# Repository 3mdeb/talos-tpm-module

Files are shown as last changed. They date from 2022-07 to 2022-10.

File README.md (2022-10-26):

# talos-tpm-module

TPM module design for
[Raptor CS Talos II](https://raptorcs.com/content/TL2WK2/intro.html) board.

**Revision 1.1 changelog:**

+ The main change is that the main connector is soldered from the bottom.

+ Jumper is also soldered from the bottom.

+ The arrangement of components has been slightly modified

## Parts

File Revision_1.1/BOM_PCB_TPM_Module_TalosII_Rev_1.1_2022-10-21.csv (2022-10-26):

ID | Name | Designator | Footprint | Quantity | Manufacturer Part | Manufacturer | Supplier | Supplier Part | Price
1 | 1uF | C1 | C1206 | 1 | CL31B105KBHNNNE | SAMSUNG | LCSC | C1848 | 0.014
2 | 100nF | C2,C3 | C1206 | 2 | CL31B104KBCNNNC | SAMSUNG | LCSC | C24497 | 0.013
3 | JUMPER2 | J1 | HDR-TH_2P-P2.54-V-M-1 | 1 | Jumper2 | null | LCSC | C2940092
4 | 4.7kΩ | R1 | R1206 | 1 | RMC12064.7K5%N | Tyohm | LCSC | C269760 | 0.007
5 | SLB9645TT12FW13333XUMA2 | U1 | PG-TSSOP-28_L9.7-W4.4-P0.65-LS6.4-BL | 1 | SLB9645TT12FW13333XUMA2 | Infineon(英飞凌) | LCSC | C2651707 | 2.584
6 | 220R-2*10P H=8.5MM Ytype Gold-plated black | H2 | HDR-TH_20P-P2.54-H-F-R2-C10-S2.54-W10.2 | 1 | 220R-2*10P H=8.5MM Ytype Gold-plated black | Ckmtw | LCSC | C124406 | 0.319

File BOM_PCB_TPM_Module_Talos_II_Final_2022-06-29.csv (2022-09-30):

ID | Name | Designator | Footprint | Quantity | Manufacturer Part | Manufacturer | Supplier | Supplier Part | Price
1 | 1uF | C1 | C1206 | 1 | CL31B105KBHNNNE | SAMSUNG | LCSC | C1848 | 0.026
2 | 100nF | C2,C3 | C1206 | 2 | CL31B104KBCNNNC | SAMSUNG | LCSC | C24497 | 0.014
3 | DS1024-2*10R2 CONNFLY | H2 | HDR-TH_20P-P2.54-H-F-R2-C10-S2.54-W10.2 | 1 | DS1024-2*10R2 | CONNFLY | TME | ZL263-20DG | 0.429
4 | 4.7kΩ | R1 | R1206 | 1 | RMC12064.7K5%N | Tyohm | LCSC | C269760 | 0.007
5 | SLB9645TT12FW13333XUMA2 | U1 | PG-TSSOP-28_L9.7-W4.4-P0.65-LS6.4-BL | 1 | SLB9645TT12FW13333XUMA2 | Infineon(英飞凌) | LCSC | C2651707 | 2.584
6 | JUMPER2 | U2 | HDR-TH_2P-P2.54-V-M-1 | 1 | Jumper2 | null | LCSC | C2940092

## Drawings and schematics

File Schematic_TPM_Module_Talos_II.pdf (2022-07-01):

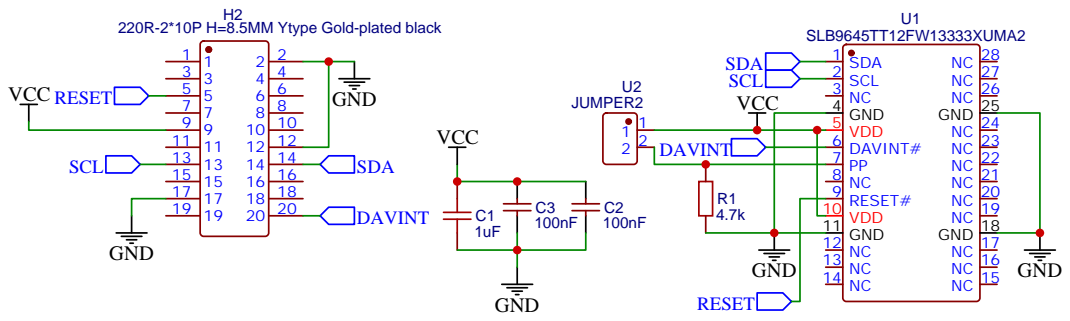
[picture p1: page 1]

220R-2*10P H=8.5MM Ytype Gold-plated black

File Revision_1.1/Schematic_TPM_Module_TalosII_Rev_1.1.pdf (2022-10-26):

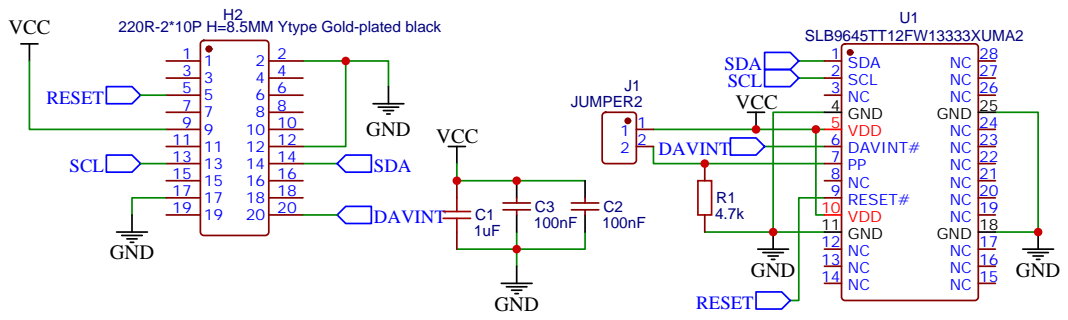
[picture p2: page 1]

220R-2*10P H=8.5MM Ytype Gold-plated black

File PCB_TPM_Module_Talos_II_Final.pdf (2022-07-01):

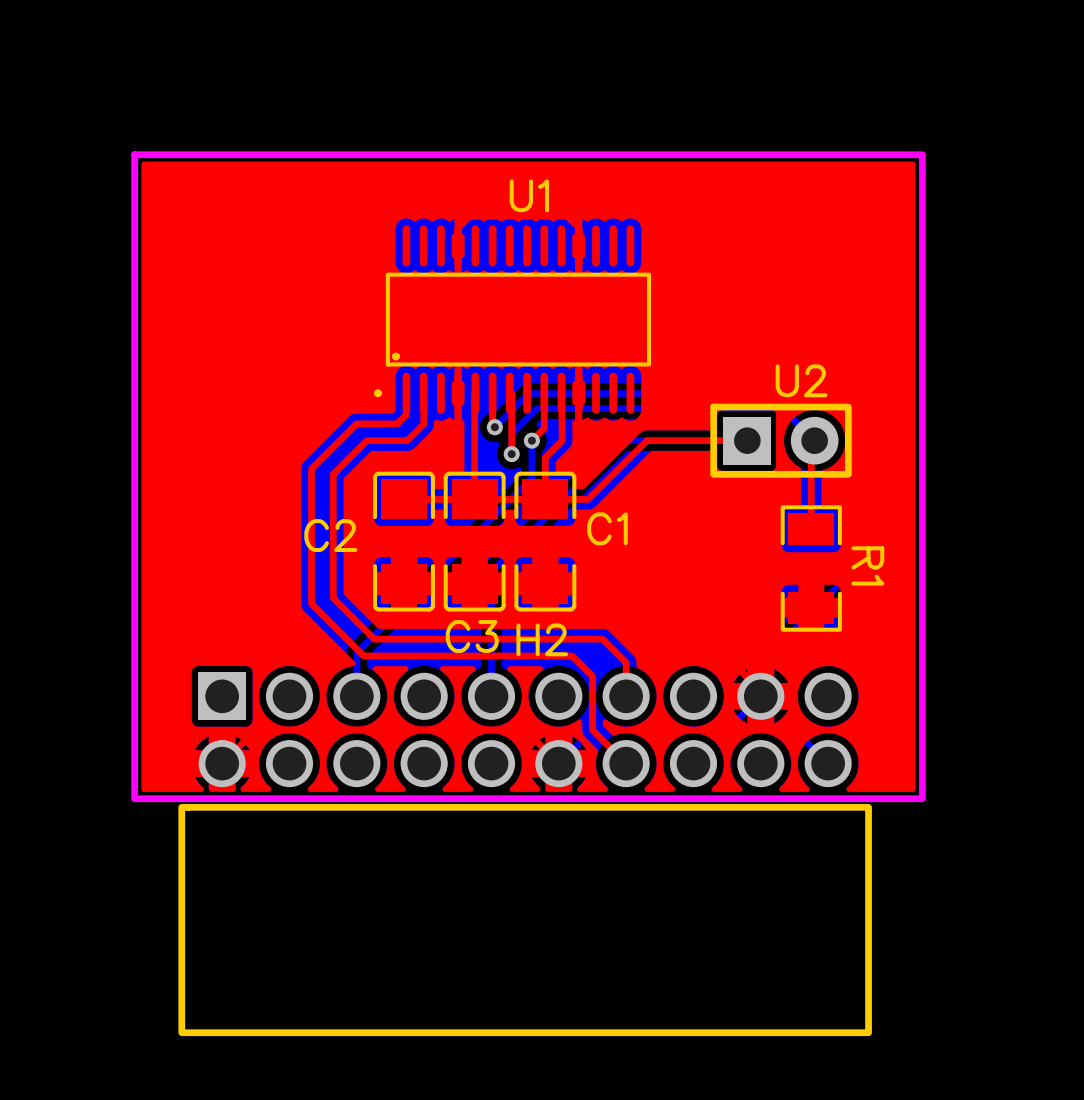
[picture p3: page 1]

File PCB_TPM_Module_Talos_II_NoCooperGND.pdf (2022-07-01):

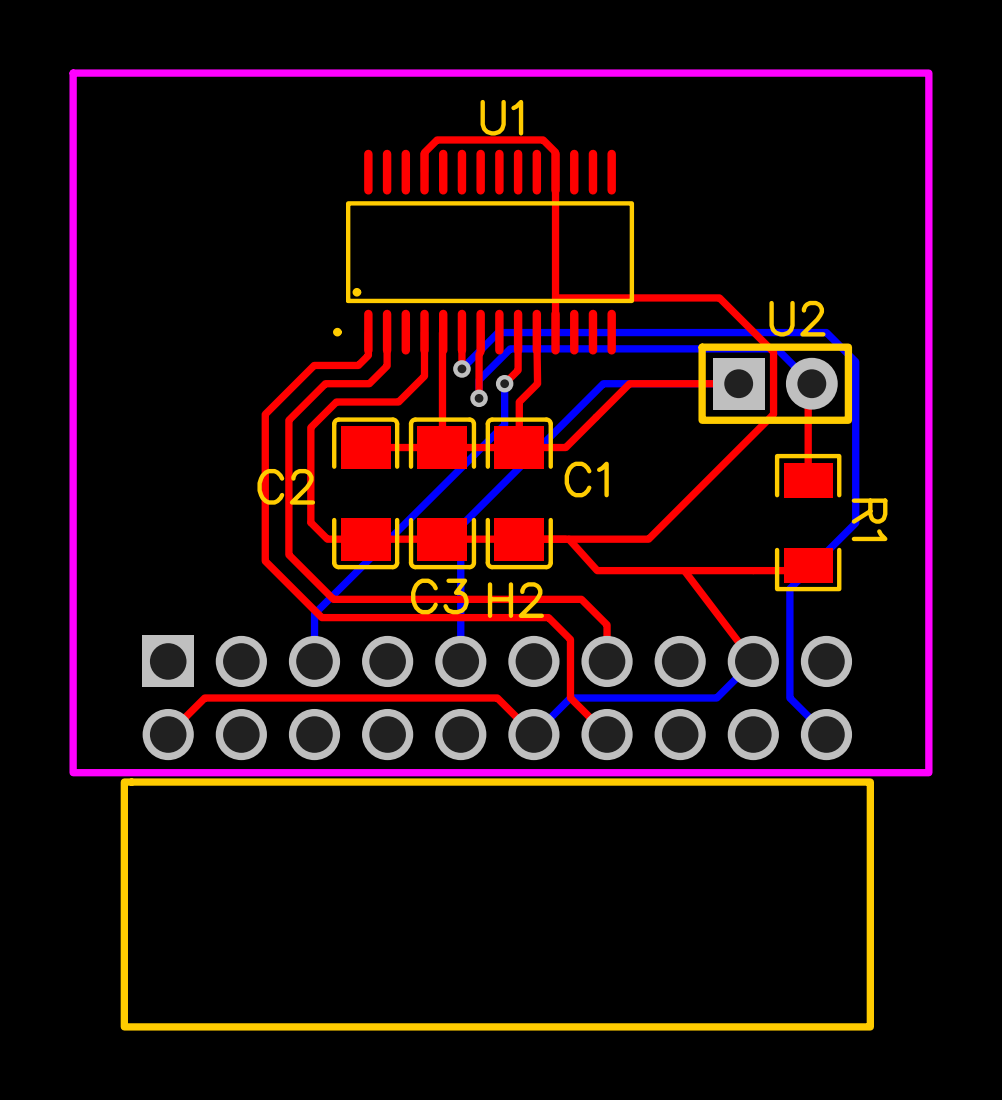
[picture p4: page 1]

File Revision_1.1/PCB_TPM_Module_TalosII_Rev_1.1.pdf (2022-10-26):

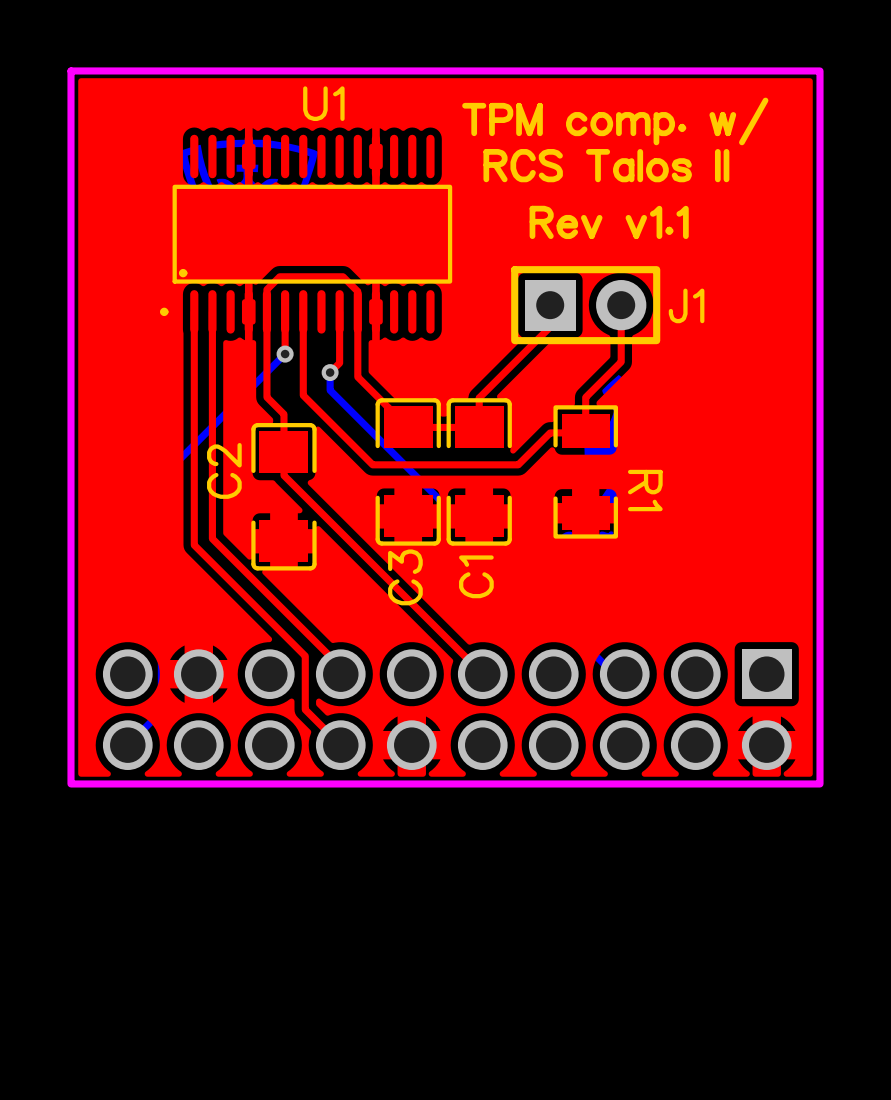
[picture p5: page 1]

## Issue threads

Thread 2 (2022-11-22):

Orientation diagram or example when connected to talos II

tlaurion, 2022-11-22:
Hello there!

The full 20 pins are open as opposed to 19 on the board connector as defined under https://github.com/3mdeb/openpower-coreboot-docs/blob/main/devnotes/tpm_over_lpc.md#talos-ii-tpm-connector

Also, the readme doesn't document what the jumper is for.

It would be interesting that next modules either block the same unavailable pin on connector and/or a picture of the module connected on the motherboard.

miczyg1, 2022-11-22:
@sulewskiprzemyslaw could you make some photos of the module being connected?

> Also, the readme doesn't document what the jumper us for.
The jumper on the TPM module is for physical presence assertion.

tlaurion, 2022-11-22:
@miczyg1 then jumper would be nice if provided as well in the package. Waiting for update, not wanting to short anything putting it in wrong orientation.

Thanks!

tlaurion, 2022-11-22:
Orientation pictures were posted at https://github.com/Dasharo/dasharo-issues/issues/192#issuecomment-1296906953

tlaurion, 2022-11-22:
Unfortunately, thé platorm doesn't boot when the module is connected (without jumper)

tlaurion, 2022-11-23:
The first picture at https://github.com/Dasharo/dasharo-issues/issues/192#issuecomment-1296906953 shows first revision of the TPM module connected to Talos motherboard.

It also shows that rev 1.1 is reversed (top is down, down is up) as compared to rev 1.1.

PrzemyslawBanasiak13, 2022-11-23:
@tlaurion currently I'm working on those issues. New documentation dedicated to TPM on Talos II will be added and it will contain:

- How/where to purchase the TPM module.
- Info about the module (e.g. about the pinout marked as `U2` on the TPM module)
- Where’s the TPM slot on the device.
- How to mount the TPM (with graphics explanations).
- How to confirm that the module works.

tlaurion, 2022-12-02:
Well, https://github.com/Dasharo/dasharo-issues/issues/272#issuecomment-1335113733 seem to confirm that my module was shorted and is now dead.

@PrzemyslawBanasiak13 : I would suggest to 3mdeb to make sure PIN #2 is blocked so that misorientation of the board, on rev 1.0/rev 1.1 of the board is not causing similar issues in the future.

Closed 2023-02-17.

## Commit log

2022-07-01 PCB project for TPM module for TalosII hardware platform - initial commit
    [PCB_TPM_Module_Talos_II_Final_AltiumDesigner.pcbdoc, SchematicAltiumdesigner.schdoc]
2022-07-01 Gerber files and BOM added
    [BOM_PCB_TPM_Module_Talos_II_Final_2022-06-29.csv]
2022-09-30 Correction in BOM file
    [BOM_PCB_TPM_Module_Talos_II_Final_2022-06-29.csv]
2022-10-21 Project files for revision 1.1 added
    [AltiumDesigner_Schematic_1_2022-10-21.schdoc, Autorouter_PCB_TPM_Module_TalosII_Rev_1.1_2022-10-21.dsn, BOM_PCB_TPM_Module_TalosII_Rev_1.1_2022-10-21.csv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]
